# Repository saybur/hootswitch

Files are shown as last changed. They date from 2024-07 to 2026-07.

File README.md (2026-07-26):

hootswitch
==========

Hootswitch is an [ADB](https://en.wikipedia.org/wiki/Apple_Desktop_Bus)
multiplexer that allows peripherals (inluding keyboards and mice) to be shared
across up to four retro computers.

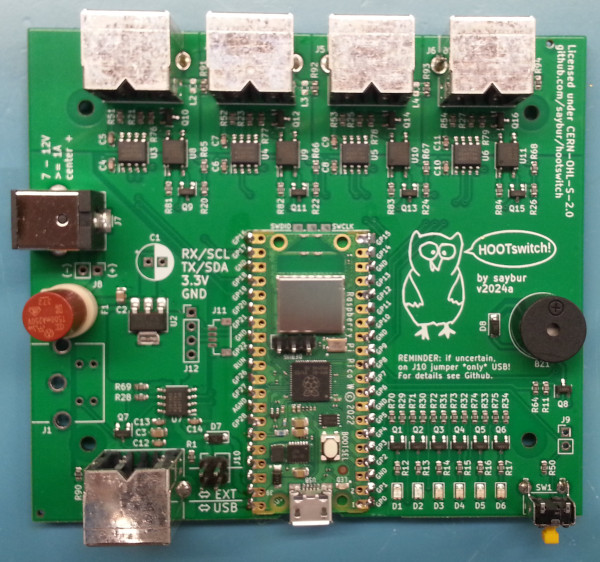
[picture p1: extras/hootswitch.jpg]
Hootswitch 2024a


This project has two parts: an example hardware design and the firmware,
located in their respective folders in this repo.

Status
------

Hootswitch is a hobby project and is very much an ongoing work-in-progress.
Bug reports and/or suggestions are welcome.

Devices that follow the standard ADB keyboard/mouse protocol are supported.
This includes most peripherals that do not have a Mac extension. While ADB was
popular many vendors created devices that required special drivers. There is
interface support for some of these:

- Kensington trackballs (Turbo Mice 4.0 and 5.0)
- Gravis joysticks (Firebird / Blackhawk / Mousestick II)

There is also experimental support for Bluetooth peripherals (both classic and
BLE) via the [Bluepad32](https://github.com/ricardoquesada/bluepad32) library.
Supported devices include
[keyboards](https://bluepad32.readthedocs.io/en/latest/supported_keyboards/),
[mice](https://bluepad32.readthedocs.io/en/latest/supported_mice/), and
[gamepads](https://bluepad32.readthedocs.io/en/latest/supported_gamepads/). By
default, gamepads default to emulating an eight-button keyboard; if you have
the Gravis Firebird driver installed on a computer the gamepad will instead
emulate that device as the extension loads.

Finally, a [fly-by-wire](https://saybur.github.io/hootswitch/flybywire/)
interface allows you to drive your retro computers from a Chromium web browser
on a modern system; this requires a direct USB connection to the Hootswitch.

The firmware is still under active development and many bugs remain. Known
issues include:

- Mouse input can be a bit "floaty" especially during extreme movements.
- No support for non-English keyboard layouts (yet).

This section will continue to be updated as progress is (hopefully) made.

Usage
-----

Hootswitch requires power to operate. For almost all users the front USB
connection of the Pico W works best. Place a jumper across (or permanently
solder) the two front-most pins on J10.

> [!CAUTION]
> __ADB does not support hot-plugging!__ Always power down the device and all
> connected computers before changing cables.

Attach ADB peripherals to the front ADB port. The port on the side of the board
(unpopulated in the picture above) may also be soldered down to provide an ADB
pass-through for more peripherals. Attach computers to the back ports; with
the USB port pointing toward you, computer 1 is the left-most port.

Switching between systems works via the button on the front or
<kbd>Control</kbd> / <kbd>Option</kbd> / <kbd>⌘</kbd> / <kbd>Shift</kbd> in
sequence, followed by <kbd>1</kbd> - <kbd>4</kbd> to choose a port.

To pair a Bluetooth device, put it into pairing mode. Once done, press and hold
the Hootswitch button for at least three seconds, then let go. The Pico W LED
will flash while in pairing mode. More LEDs will light up and the buzzer will
play a tone as the device connects. Hold down the button for more than ten
seconds to remove all paired devices from memory.

Hootswitch logs its status over the USB connection, which may help diagnose
issues with device pairing (or other problems). To view the log, use your
favorite terminal emulator or the fly-by-wire interface.

To update the firmware, make sure your power selection is set for USB, then
hold down the BOOTSEL button while you plug in to your computer via USB. Copy
the correct `.uf2` onto the new mass storage device that appears. Once done the
Pico will disconnect automatically.

Licenses
--------

Except where otherwise noted, all software is available under the Mozilla
Public License (MPL) 2.0. The example hardware is available under the CERN Open
Hardware Licence strongly-reciprocal variant, version 2. Refer to the licenses
for specific terms.

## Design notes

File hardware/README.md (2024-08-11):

Hootswitch Hardware
===================

This folder has the hardware design being used to develop the firmware. Known
issues with it include:

- Some features are untested, including alternate power modes.
- C1 in the BOM is wrong. Since I am not using the power input at the moment I
  left it unpopulated.
- There is no keepout for the wireless chip, which may negatively impact
  reception.
- Annular rings on the mini-DIN connectors are on the small side.
- Green LEDs are too bright. Adjusted in 2024a with PWM. Future revision needs
  stronger resistors.
- Mounting holes are too small for the standard screws. These are also a tad
  too close to the connectors.
- A connection should be made between host power-on and a free GPIO. This can
  be worked around in software with keyboards.
- It might have been wiser to put bus input pins to GPIOs with PWM B inputs.
  This will probably not be changed, PIO handles everything fine.

Anticipate that a future revision will be made with corrections.
[CHANGES.txt](CHANGES.txt) will have any applicable history.

This project is made available under the CERN Open Hardware Licence
strongly-reciprocal variant version 2, available at [LICENSE](LICENSE).

This is distributed WITHOUT ANY EXPRESS OR IMPLIED WARRANTY, INCLUDING OF
MERCHANTABILITY, SATISFACTORY QUALITY AND FITNESS FOR A PARTICULAR PURPOSE.
Please see the CERN-OHL-S v2 for applicable conditions.

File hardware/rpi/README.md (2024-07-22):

# Raspberry Pi Pico Files

See `LICENSE` for distribution. See
<https://github.com/HeadBoffin/RP_Silicon_KiCad> for the original source.

The `.kicad_sym` file was derived from the above and retains its license.

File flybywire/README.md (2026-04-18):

Fly-By-Wire
===========

The web portion of the serial link control system used by Hootswitch. Visit
<https://saybur.github.io/hootswitch/flybywire/> to access.

External Dependencies
---------------------

- `simple_keyboard.js` and `simple-keyboard.css` are from the
[Simple Keyboard](https://github.com/hodgef/simple-keyboard) project.
- `keyboard-capture.js` and `keyboard-capture.css` are from the
[IP-KVM-InterFace](https://github.com/SterlingButters/ip-kvm-interface)
project. Refer to those files for license information.

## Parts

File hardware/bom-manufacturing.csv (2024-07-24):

Designator | Comment | Footprint | LCSC Part Number
C2-3 | 10uF | 805 | C15850
C4-14 | 100nF | 603 | C14663
D1 | LED | 805 | C84256
D2 | LED | 805 | C2296
D3-6 | LED | 805 | C2297
D7-8 | B5819W | SOD-123 | C8598
Q1-16 | MMBT3904 | SOT-23 | C20526
R1 | 470ohm | 603 | C23179
R11-17 | 1Kohm | 603 | C21190
R20-34 | 2K2ohm | 603 | C4190
R50-54 | 4K7ohm | 603 | C23162
R64-79 | 10Kohm | 603 | C25804
R81-84 | 330ohm | 603 | C23138
R90-94 | 0ohm | 603 | C21189
U2 | AMS1117-5.0 | SOT-223 | C6187
U3-7 | ADUM1201ARZ-RL7 | SOIC-8 | C9669
U8-11 | EL357N(C) | SOP-4-2.54mm | C29981

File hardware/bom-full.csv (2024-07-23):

refs | count | desc | jlcpcb | jlcpcb_fp | digikey | notes | cost_est
BZ1 | 1 | Buzzer |  |  | 668-1456-ND | optional | 1.25
C1 | 1 | 100uF |  |  | P1370-ND |  | 0.3
C2-3 | 2 | 10uF | C15850 | 805 |  |  | 0.1
C4-14 | 11 | 100nF | C14663 | 603 |  |  | 0.01
D1 | 1 | LED | C84256 | 805 |  | red | 0.01
D2 | 1 | LED | C2296 | 805 |  | yellow | 0.01
D3-6 | 4 | LED | C2297 | 805 |  | green | 0.01
D7-8 | 2 | B5819W | C8598 | SOD-123 |  |  | 0.02
F1 | 1 | Fuse Holder |  |  | WK0001-ND |  | 0.96
J1-6 | 6 | Mini-DIN-4-G |  |  | 5749181-1-ND | J1 optional | 2
J7 | 1 | Barrel_Jack_MountingPin |  |  | PJ-063AH | optional | 1.61
J8-9 | 1 | 1x2 Pins |  |  | 2057-PH1-02-UA-ND | optional | 0.1
J10 | 1 | 2x2 Pins |  |  | 2057-PH2-04-UA-ND |  | 0.1
J11 | 1 | TWI Connector |  |  | 455-BM04B-SRSS-TBCT-ND | optional | 0.62
J12 | 1 | TWI Connector |  |  | 2057-PH1-04-UA-ND | optional | 0.1
Q1-16 | 16 | MMBT3904 | C20526 | SOT-23 |  |  | 0.01
R1 | 1 | 470ohm | C23179 | 603 |  |  | 0.01
R11-17 | 7 | 1Kohm | C21190 | 603 |  |  | 0.01
R20-34 | 15 | 2K2ohm | C4190 | 603 |  |  | 0.01
R50-54 | 5 | 4K7ohm | C23162 | 603 |  |  | 0.01
R64-79 | 16 | 10Kohm | C25804 | 603 |  |  | 0.01
R81-84 | 4 | 330ohm | C23138 | 603 |  |  | 0.01
R90-94 | 5 | 0ohm | C21189 | 603 |  |  | 0.01
SW1 | 1 | Switch1 |  |  | SW410-ND |  | 0.33
U1 | 1 | Pico W |  |  | 2648-SC0918CT-ND |  | 6
U2 | 1 | AMS1117-5.0 | C6187 | SOT-223 |  |  | 0.15
U3-7 | 5 | ADuM1201AR | C9669 | SOIC-8 |  |  | 1.01
U8-11 | 4 | EL357N(C) | C29981 | SOP-4-2.54mm |  |  | 0.05
- | 1 | switch cap |  |  | SW1139-ND | or similar | 0.95
- | 1 | off-the-shelf case |  |  | HM1093-ND | RM2015S | 6.08
- | 2 | 500mA Fuses |  |  | WK4241BK-ND |  | 0.92

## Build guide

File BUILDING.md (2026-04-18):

Building
========

## Setup

You will need the correct tools to build the firmware. There is a setup script
[here](https://raw.githubusercontent.com/raspberrypi/pico-setup/master/pico_setup.sh)
that assumes you're using a Raspberry Pi as your development environment if you
want to try that; I personally use Debian _trixie_ on a regular x86 system
instead, set up as follows.

Dependencies and associated tools:

```
sudo apt install git cmake gcc-arm-none-eabi gcc gdb-multiarch automake \
    autoconf build-essential texinfo libtool libftdi-dev libusb-1.0-0-dev \
    openocd
```

## Clone the Project

Project dependencies are provided as Git submodules. Clone the project, then
execute `git submodule update --init` within the local working tree. If you do
not have a separate Pico SDK installed you will also need to pull its
submodules with `git submodule update --init --recursive`.

### Optional: Separate pico-sdk

If you have multiple Pico projects (or limited storage space) you may want a
separate copy of the SDK. If `PICO_SDK_PATH` is defined that will be used
instead of the submodule. This part can be skipped if you already used the
`--recursive` version above.

Clone the [Pico SDK](https://github.com/raspberrypi/pico-sdk). Execute
`git submodule update --init` in that project to get sub-libraries added. Set
`PICO_SDK_PATH` to point at where the SDK lives via `~/.bashrc` or equivalent;
something like `export PICO_SDK_PATH=/home/saybur/src/pico-sdk` would be
suitable after being adjusted for your environment.

## Build the Firmware

Once you have everything set up, build as follows from the root of the repo.
This builds for the Pico W by default. To build for the standard (non-W) Pico,
pass `-DPICO_BOARD=pico` during the call to `cmake` below.

```
mkdir -p build
cd build
cmake ..
make -j4
```

Among other files, this will produce `hootswitch.uf2`. Flash it to the device
following the instructions in <README.md>.

## Hardware

Both the original Raspberry Pi Pico and Pico W boards are supported. The focus
of development is on the Pico W: in addition to support for Bluetooth, the
current configuration system also requires the _btstack_ library, which is
licensed for use on the Pico W only.

The Pico 2 and Pico 2 W have _not_ been tested and may not work correctly.

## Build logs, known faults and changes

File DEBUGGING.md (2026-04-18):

Debugging
=========

These are notes for a potential way to debug the device during development.
This is how I (@saybur) personally like working on it in a Linux desktop
environment.

Logging
-------

Hootswitch will log some aspects of device detection, host startup, and similar
lifecycle events to the USB CDC device. Connect at 115200 baud, 8-N-1.

Hardware
--------

To capture ADB signals I use an inexpensive logic analyzer compatible with the
`fx2lafw` firmware from the
[sigrok](https://sigrok.org/wiki/Main_Page) project. To sample the device-side
the passthrough ADB connector works great. For one of the hosts you can either
use the second ADB port on a computer that has one (IIci and the like) or a
hacked-together ADB splitter of some kind.

[PulseView](https://sigrok.org/wiki/PulseView) works for reviewing captures. It
works even better with an ADB decoder like
[decoder-adb](https://github.com/tmk/decoder-adb). On my system that had to be
installed in ` ~/.local/share/libsigrokdecode/decoders` in an `adb` subfolder.

Software
--------

You will want to invoke `cmake` with `-DCMAKE_BUILD_TYPE=Debug`.

[The official debugger](https://www.raspberrypi.com/documentation/microcontrollers/debug-probe.html)
is dirt cheap and works reasonably well if you plan to develop on the firmware.
It can be used as follows to upload without needing to fuss with the BOOTSEL
button. Be in the `dialout` group to avoid needing `sudo` all over the place.
OpenOCD can be started as follows.

```
openocd -c "set USE_CORE 0" -f interface/cmsis-dap.cfg -f target/rp2040.cfg \
    -c "adapter speed 5000" -c "rp2040.core0 configure -rtos FreeRTOS"
```

See <https://github.com/raspberrypi/pico-sdk/issues/1622> for a discussion
about `USE_CORE 0` above. The above is fine for now with the current state of
development, which runs only on a single core anyway.

In another terminal, run `gdb-multiarch hootswitch.elf`. Connect to the device
with `target remote localhost:3333` (or automate this step via `~/.gdbinit`).
See [the documentation](https://openocd.org/doc/html/General-Commands.html) for
specifics; the following commands are likely useful (with the caveat that I am
_most definitely_ not an authority on `gdb`):

* `load` will update programming with the current ELF.
* `monitor reset init` will restart and halt for instructions.
* `print X` prints information about something, including variables.
* `br X` adds a breakpoint at X, `del` removes one or more.
* `continue` will proceed, stopping at breakpoints; Ctrl-C halts.
* `finish` completes a function.
* `bt` prints a backtrace, `bt f` prints a backtrace with symbols.
* `up` and `down` moves around the frames of a call.
* `i r` prints registers.
* `p X` prints variable X.
* `p/x *0x0` prints in hex from the address, useful for peripheral registers.
* `i threads` prints information relevant to FreeRTOS thread execution.

Use `arm-none-eabi-size -A hootswitch.elf` to get an idea about RAM usage.

If compiled with `RUNTIME_FREERTOS_REPORTING` additional serial commands are
made available to invoke various FreeRTOS task reporting functions. To use,
invoke `cmake` with `-DRUNTIME_FREERTOS_REPORTING=1`. Refer to `control.h` and
`debug.h` for a list of commands.

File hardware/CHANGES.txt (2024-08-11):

DESIGN CHANGES

Refer to section 3.3.b of the license for information that must be included in
this document.

- 23 July 2024, rev 2024a: first design

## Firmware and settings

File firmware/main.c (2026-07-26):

/*
 * Copyright (C) 2024-2026 saybur
 *
 * This Source Code Form is subject to the terms of the Mozilla Public
 * License, v. 2.0. If a copy of the MPL was not distributed with this
 * file, You can obtain one at https://mozilla.org/MPL/2.0/.
 */

#include <stdio.h>
#include <stdbool.h>
#include "pico/stdlib.h"
#include "hardware/gpio.h"

#include "FreeRTOS.h"
#include "task.h"

#include "button.h"
#include "buzzer.h"
#include "computer.h"
#include "config.h"
#include "control.h"
#include "debug.h"
#include "driver.h"
#include "host.h"
#include "hardware.h"
#include "led.h"
#include "notify.h"
#include "usb.h"

#ifdef HOOTSWITCH_WIRELESS
#include "bt.h"
#endif

#define PROGRAM_NAME       "hootswitch-v20270726b"

#define DEFAULT_STACK      configMINIMAL_STACK_SIZE
#define DEFAULT_PRIORITY   (tskIDLE_PRIORITY + 1U)
#define DISPATCH_PRIORITY  (tskIDLE_PRIORITY + 8U)

// https://stackoverflow.com/a/2220565
#pragma GCC push_options
#pragma GCC optimize ("O0")
void vApplicationStackOverflowHook(TaskHandle_t xTask, char *pcTaskName)
{
	led_error_on();
	dbg_err("___stack overflow!___ %s", pcTaskName);
	while (1);
}
#pragma GCC pop_options

static void init_hardware(void)
{
	led_init();

	buzzer_init();
	host_init();
	computer_init();

	// setup input switch
	gpio_init(SWITCH_PIN);
	gpio_pull_up(SWITCH_PIN);
}

static void init_config(void)
{
	// already performed within BT code, skip
	// config_setup();

	// read core configuration information, and on failure leave at defaults
	uint8_t core;
	if (config_read(CONFIG_OFFSET_BASE, &core, 1)) {
		return;
	}

	if (! (core & 1)) {
		buzzer_enable(false);
	}
}

static void init_task(__unused void *parameters)
{
	// wait for USB enumeration, and for ADB devices to power up themselves up
	busy_wait_ms(1600);

	// handle alternate startup conditions
	switch (control_check_reset()) {
		case RESET_TYPE_DEBUG:
			// wait for a USB UART to connect
			bool led = false;
			while (! stdio_usb_connected()) {
				vTaskDelay(100);
				if (led) {
					led_activity_on();
				} else {
					led_activity_off();
				}
				led = !led;
			}
			led_activity_off();
			break;
	}

	dbg(PROGRAM_NAME);
	led_activity_on();

#ifdef HOOTSWITCH_WIRELESS
	// need btstack loaded to get TLV config
	volatile bool started = false;
	bt_init(&started);
	while (!started) tight_loop_contents();
#endif

	init_config();
	handler_init();

	host_err herr;
	if (herr = host_reset_bus()) {
		dbg_err("host bus reset err %d", herr);
		notify_user(NOTIFY_HOST_INIT_RESET_FAIL);
	}
	busy_wait_ms(1);
	if (herr = host_reset_devices()) {
		dbg_err("host device reset err %d", herr);
		notify_user(NOTIFY_HOST_INIT_NO_DEVICES);
	} else {
		dbg("host reset ok!");
	}

	driver_init();
	computer_start();

	xTaskCreate(computer_task, "computer", DEFAULT_STACK,
			NULL, DISPATCH_PRIORITY, NULL);
	xTaskCreate(host_task, "host", DEFAULT_STACK,
			NULL, DISPATCH_PRIORITY, NULL);
	xTaskCreate(button_task, "button", DEFAULT_STACK,
			NULL, DEFAULT_PRIORITY, NULL);
	xTaskCreate(control_task, "control", configMINIMAL_STACK_SIZE,
			NULL, DEFAULT_PRIORITY, NULL);

	// may be vulnerable to drivers not being hooked but we'll try anyway
	computer_switch(1, true);

	vTaskDelete(NULL);
}

int main(void)
{
	usb_dev_init();
	stdio_init_all();

	init_hardware();
	dbg_init();

	xTaskCreate(init_task, "init", DEFAULT_STACK,
			NULL, DEFAULT_PRIORITY, NULL);
	xTaskCreate(usb_dev_task, "usb_dev", DEFAULT_STACK * 3,
			NULL, configMAX_PRIORITIES - 1, NULL);
	xTaskCreate(dbg_task, "debug", DEFAULT_STACK,
			NULL, configMAX_PRIORITIES - 2, NULL);
	xTaskCreate(notify_task, "notify", DEFAULT_STACK,
			NULL, DEFAULT_PRIORITY, NULL);

	vTaskStartScheduler();
}

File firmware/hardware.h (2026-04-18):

/*
 * Copyright (C) 2024-2026 saybur
 *
 * This Source Code Form is subject to the terms of the Mozilla Public
 * License, v. 2.0. If a copy of the MPL was not distributed with this
 * file, You can obtain one at https://mozilla.org/MPL/2.0/.
 */

#ifndef __HARDWARE_H__
#define __HARDWARE_H__

/*
 * ----------------------------------------------------------------------------
 *     PIN DEFINITIONS
 *   Change these to match your hardware.
 * ----------------------------------------------------------------------------
 *
 * The RP2040 has fewer "gotchas" than other MCUs but there still are some
 * limitations to be aware of if you're trying a new board spin:
 *
 * - LEDs should not be on PWMs shared with other periphals that use the PWM
 *   system, such as the buzzer, or you will need to adjust the LED driving
 *   code.
 * - Generally try to have the _DO lines on PWM_CHB (odd GPIOs), they are the
 *   only ones with duty cycle / frequency measuring. This is not currently
 *   implemented, PIO handles all that stuff, but it might be useful in the
 *   future.
 */

#define LED_ERR_PIN         0
#define LED_ACT_PIN         1
#define LED_C1_PIN          2
#define LED_C2_PIN          3
#define LED_C3_PIN          4
#define LED_C4_PIN          5
#define SWITCH_PIN          6
#define BUZZER_PIN          7
#define A_DO_PIN            26
#define A_DI_PIN            27
#define C1_DO_PIN           18
#define C1_DI_PIN           19
#define C1_PSW_PIN          17
#define C2_DO_PIN           15
#define C2_DI_PIN           16
#define C2_PSW_PIN          14
#define C3_DO_PIN           12
#define C3_DI_PIN           13
#define C3_PSW_PIN          11
#define C4_DO_PIN           9
#define C4_DI_PIN           10
#define C4_PSW_PIN          8

/*
 * First revision hardware has green LEDs that are quite eye-piercing. To tone
 * it down this value is used by LED setting code to tweak the PWM level (from
 * 0-255) of those elements.
 */
#define LED_MACHINE_LEVEL   70

/*
 * ----------------------------------------------------------------------------
 *     RESOURCE DEFINITIONS / ALIASES
 *   Use care changing anything past this line!
 * ----------------------------------------------------------------------------
 */

// "computer" refers to the emulated device ports on the back
#define COMPUTER_PIO        pio0
#define COMPUTER_PIO_IRQ0   PIO0_IRQ_0
#define COMPUTER_COUNT      4

// device DMA units, used to handle initial signal detection and Listen data
#define COMPUTER_DMA_IRQ    DMA_IRQ_1
#define COMPUTER_DMA_IDX    1
#define COMPUTER_DMA_INTS   dma_hw->ints1
#define COMPUTER_0_DMA      6
#define COMPUTER_1_DMA      7
#define COMPUTER_2_DMA      8
#define COMPUTER_3_DMA      9

// additional DMA channel used for handling configuration data
#define CONFIG_DMA_CHAN     5

// "host" refers to the connection with the native peripherals on the front
#define HOST_PIO            pio1
#define HOST_PIO_IRQ0       PIO1_IRQ_0

#define COMPUTER_TIMER      1
#define COMPUTER_TIMER_IRQ  TIMER_IRQ_1
#define HOST_TIMER          0
#define HOST_TIMER_IRQ      TIMER_IRQ_0

#define A_DO_PIN_bm         (1U << A_DO_PIN)
#define C1_DO_PIN_bm        (1U << C1_DO_PIN)
#define C2_DO_PIN_bm        (1U << C2_DO_PIN)
#define C3_DO_PIN_bm        (1U << C3_DO_PIN)
#define C4_DO_PIN_bm        (1U << C4_DO_PIN)

#define A_DO_PIN_bm         (1U << A_DO_PIN)
#define C1_DO_PIN_bm        (1U << C1_DO_PIN)
#define C2_DO_PIN_bm        (1U << C2_DO_PIN)
#define C3_DO_PIN_bm        (1U << C3_DO_PIN)
#define C4_DO_PIN_bm        (1U << C4_DO_PIN)

#endif /* __HARDWARE_H__ */

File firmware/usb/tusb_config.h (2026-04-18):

/*
 * The MIT License (MIT)
 *
 * Copyright (c) 2019 Ha Thach (tinyusb.org)
 *
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
 */

#ifndef _TUSB_CONFIG_H_
#define _TUSB_CONFIG_H_

#ifdef __cplusplus
 extern "C" {
#endif

//--------------------------------------------------------------------+
// Board Specific Configuration
//--------------------------------------------------------------------+

// RHPort number used for device can be defined by board.mk, default to port 0
#ifndef BOARD_TUD_RHPORT
#define BOARD_TUD_RHPORT     0
#endif

// RHPort max operational speed can defined by board.mk
#ifndef BOARD_TUD_MAX_SPEED
#define BOARD_TUD_MAX_SPEED   OPT_MODE_DEFAULT_SPEED
#endif

//--------------------------------------------------------------------
// COMMON CONFIGURATION
//--------------------------------------------------------------------

// defined by board.mk
#ifndef CFG_TUSB_MCU
#error CFG_TUSB_MCU must be defined
#endif

// saybur note: overwritten by lib/tinyusb/hw/bsp/rp2040/family.cmake
// see https://github.com/raspberrypi/pico-sdk/issues/1326
// worked around in usb.c
#ifndef CFG_TUSB_OS
#define CFG_TUSB_OS           OPT_OS_FREERTOS
#endif

// Espressif IDF requires "freertos/" prefix in include path
#if TUP_MCU_ESPRESSIF
#define CFG_TUSB_OS_INC_PATH  freertos/
#endif

// can be defined by compiler in DEBUG build
#ifndef CFG_TUSB_DEBUG
#define CFG_TUSB_DEBUG        0
#endif

// Enable Device stack
#define CFG_TUD_ENABLED       1

// Default is max speed that hardware controller could support with on-chip PHY
#define CFG_TUD_MAX_SPEED     BOARD_TUD_MAX_SPEED

/* USB DMA on some MCUs can only access a specific SRAM region with restriction on alignment.
 * Tinyusb use follows macros to declare transferring memory so that they can be put
 * into those specific section.
 * e.g
 * - CFG_TUSB_MEM SECTION : __attribute__ (( section(".usb_ram") ))
 * - CFG_TUSB_MEM_ALIGN   : __attribute__ ((aligned(4)))
 */
#ifndef CFG_TUSB_MEM_SECTION
#define CFG_TUSB_MEM_SECTION
#endif

#ifndef CFG_TUSB_MEM_ALIGN
#define CFG_TUSB_MEM_ALIGN    __attribute__ ((aligned(4)))
#endif

//--------------------------------------------------------------------
// DEVICE CONFIGURATION
//--------------------------------------------------------------------

#ifndef CFG_TUD_ENDPOINT0_SIZE
#define CFG_TUD_ENDPOINT0_SIZE   64
#endif

//------------- CLASS -------------//
#define CFG_TUD_CDC              1
#define CFG_TUD_MSC              0
#define CFG_TUD_HID              0
#define CFG_TUD_MIDI             0
#define CFG_TUD_VENDOR           0

// CDC FIFO size of TX and RX
#define CFG_TUD_CDC_RX_BUFSIZE   256
#define CFG_TUD_CDC_TX_BUFSIZE   256

// CDC Endpoint transfer buffer size, more is faster
#define CFG_TUD_CDC_EP_BUFSIZE   64

// MSC Buffer size of Device Mass storage
//#define CFG_TUD_MSC_EP_BUFSIZE   512

#ifdef __cplusplus
 }
#endif

#endif /* _TUSB_CONFIG_H_ */

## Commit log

2024-07-22 Initial hardware design for v2024a.
    [hootswitch-computers.kicad_sch, hootswitch.kicad_pcb, hootswitch.kicad_sch]
2024-07-23 Switch to using proper digital isolator for data lines.
    [hootswitch-computers.kicad_sch, hootswitch.kicad_pcb, hootswitch.kicad_sch]
2024-07-23 Refinements for v2024a during BOM creation.
    [hootswitch-computers.kicad_sch, hootswitch.kicad_pcb, hootswitch.kicad_sch]
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2024-07-23 Initial BOM
    [bom-full.csv]
2024-07-23 Add TWI and second DIN connector, update BOM.
    [bom-full.csv, bom-manufacturing.csv, hootswitch.kicad_pcb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]
2024-07-24 hardware v2024a finalized
    [bom-manufacturing.csv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]
2024-07-25 Untested first draft of simple relay-style switch implementation.
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2024-08-01 Snapshot of ongoing development.
    More PIO, including trying to cut out pin interrupts, and the start of a basic program framework.
2024-08-02 Building out more of the basic program framework.
2024-08-04 First command issued on the prototype hardware! :tada:
    Otherwise just lots and lots of other changes, including documentation for what I'm intending the device/handler subsystem to look like.
    [buzzer.c, device.c]
2024-08-04 Initial host reset/readdr function added.
    Performs basic reg3 talk and listen on a Design keyboard!
    Also includes driver and handler API work.
    [host.c]
2024-08-05 Untested prototype of async host, handler API adjustments.
2024-08-07 Idle polling works! (for at least one device)
2024-08-09 Initial device-side tweaks to PIO, mostly trying to reduce CPU IRQs.
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2024-08-10 Move complexity away from timing-sensitive Tlt to attention.
    More of the skeleton for the device/machine written out.
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2024-08-11 Add mouse, basic switching now works.
    Also improved the host iteration stage to get closer to how real computers handle devices.
    Many many bugs remain but this is finally at proof-of-concept stage!
    [computer.c, host.c, main.c]
2024-08-11 Note keepout issue on wireless chip.
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2024-08-12 Smooth out mouse and fix mis-clicking.
    Still a hack but should be an acceptable foundation for a real driver now.
2024-08-14 Minimally functional FreeRTOS task replacement for the main loop.
    [computer.c, host.c]
2024-08-15 Use PIO to avoid inconsistent host-side Tlt timing.
    In addition to better Tlt reliability this removes a major use of the hardware timer and simplifies the host state machine.
    [host.c]
2024-08-15 Remove pin reset for host SM.
    Should no longer be needed with improvements in the PIO/host handler making the xmit routine a bit more deterministic.
    [host.c]
2024-08-15 Bump priority of host/comp dispatchers, add task notifiers for them.
    Keeps the scheduler from wasting time in the busy-loops of the handler/driver poll tasks and reduces the number of lost mouse update events.
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2024-08-16 More robust mouse driver, multiple handler/driver changes.
    Fixes a nasty null bug in the driver reset code and removes the polling methods. Drivers can now roll their own via a FreeRTOS task if they really need this functionality.
    Also made the host reset a one-time event; given ADB can't be hotplugged this is probably fine. Will need a bit more work to finalize this.
    [computer.c, host.c]
2024-08-17 Keyboard driver updated with some of the mouse code changes.
    Queue unused currently, will be integrated in next few commits.
2024-08-18 Change driver id to ref number, reorg driver Talk data store.
    Also SRQ is now by address again.
2024-08-18 Added queue system for drivers, keyboard is much more robust now.
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2024-08-19 New set/offer entries to computer Talk registers.
    Mouse updated to use these. Might be a bit more responsive, still not sure it's 1:1 versus the direct-attached mouse.
2024-08-19 Tweaks to keyboard switch logic based on testing.
2024-08-21 Simple button implementation for switching the active computer.
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2024-08-25 Support for keyboard LEDs and Register 2.
    This will still need handling for locking Caps Lock keys (or errata for users that you probably shouldn't lock and switch)
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2024-09-01 Move basic CDC to custom TinyUSB setup and FreeRTOS task.
    Also move init code to task to allow USB printf() to work during startup.
2024-09-08 Fix issue with errant SRQs getting issued.
    This seems to happen with the keyboards, maybe something to do with the address shuffle? Makes sure the flag gets cleared when there is no data to send.
    [computer.c]
2026-04-05 Split keyboard support into separate files.
    Driver (virtualized interface) and handler (real device) don't need to be together: separate concerns, allow better reuse of the driver side, and make the files a bit more readable.
2026-04-05 Cleanup and bugfixes from previous driver splits.
2026-04-05 Switch serial to use the new mouse/keyboard drivers.
2026-04-05 Split joystick support into separate driver/handler.
    Same idea as with keyboards and mice earlier: separate concerns, code reuse, etc.
2026-04-05 Barebones bluepad32 library integration.
    Doesn't do anything useful yet but is able to see information from a paired BLE mouse, so that's something I suppose.
    [btstack_config.h, main.c]
2026-04-09 Create a single set of virtual devices to pool inputs.
    Idea is to make serial input share with future devices to cut down on the total number of ADB devices on a computer bus.
2026-04-09 Fix un-inited variable caught by -fanalyzer
    [computer.c]
2026-04-09 Minimally-working bluepad32 integration now no longer crashes.
    Previously work was being executed on random threads, an obvious no-no with btstack. See notes in code for the resolution.
    [led.c, main.c]
2026-04-10 Compact virtual mouse movement into smaller ADB submissions via a queue.
    Ironically I think this makes the mouse feel /worse/ but having some non-blocking method to avoid stalling the BT thread is more important. Will tackle junky mouse feel in a later change.
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2026-04-11 Increase priority of virtual mouse sampler.
    Seems to slightly (?) improve virtual mouse tracking but it's hard to tell. This may eventually need to be fixed by moving some work to core1.
2026-04-11 BT scan only on startup or on-demand.
    Invoked either via flybywire or long (>3s) button press.
2026-04-11 Barely-working gamepad support.
    With a PS5 Dualsense this brings the device down to a crawl, particularly with more than 1 BT peripheral (though it's bad all the time). Suspect it's at the limit of processing with everything on 1 c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
2026-04-12 Suppress extra debug statements for now.
    Seems to be causing some stdio stalls, not sure exactly where yet.
2026-04-12 Log system tweaks.
    Time in ms, single printf per call, set bluepad32 to use same format, and add trace logging.
    Was getting intermittent hardfaults before on heavy log activity, hopefully the trace logs will help narrow down what's going on there.
2026-04-12 Fix mouse buttons being pressed on serial startup.
    The mouse send protocol still needs work, it's quite jittery on fast movement.
2026-04-12 Remove old config system in favor of btstack TLV keys.
    Still needs a lot of thought about how to configure the device. I dislike the web interface, considering whether a Mac side client would be better.
    This will also break config on non-W Picos. That's not ideal but I have concerns about the maintainability of the old system, particularly if SMP gets added.
2026-04-13 Give a bit more of a window for BT devices to connect.
2026-04-13 Note changes in device support and add some additional usage information.
2026-04-14 Simplify building for a standard Pico and note lack of testing on Pico 2.
2026-04-14 Trace logging now disabled until a restart triggered by serial request.
2026-04-14 Move rapid-fire debug statements to trace instead.
    These bog down the USB connection and should only be active in special cases.
2026-04-15 Use a queue for thread safety on stdio.
    AFAIK this should be guaranteed by the SDK but I keep having hardfaults from assert failures in that component, hopefully restricting writes to a single thread will stop that.
    [main.c]
2026-04-15 Tweaks to tone down the buzzer.
    No idea if this is "better" but feedback would be appreciated. Or a better algorithm, the buzzer isn't amazing but it still seems like it could be a little less harsh.
    [buzzer.c]
2026-04-16 Allow trace logging to be disabled/enabled via button on fly-by-wire.
2026-04-16 Handle edge case in bluepad32 joystick position data.
2026-04-17 Centralize notifications and add BT connect/disconnect tone.
    Also adds a flash code error system instead of the simple on/off, and makes the error/activity LEDs one-line set/clears.
    The buzzer is no longer an interrupt, which it really didn't need to be with FreeRTOS around.
    [buzzer.c, computer.c, hardware.h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]
2026-04-17 Tweak tasks priorities, move ADB above BT.
    It seems like this does a better job of maintaining good ADB device response and keeps BT from hogging the CPU.
2026-04-18 Add a simple LED set/clear system for BT devices to supplement the buzzer.
    [computer.c, hardware.h, led.c]
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2026-04-18 Switch flybywire to use SLIP to send commands in frames.
    This should be more forward-compatible as new features are added.
    [main.c]
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2026-04-19 Changes to joystick handling.
    Three interwoven items:
    - Back to using x1/y1 and x2/y2 as data representation.
    - Moving gamepads from using throttle/brake to axis_rx/axis_ry, which is (probably?) more useful for the variety of twin-stick gamepads out there.
    - Move digital buttons around to use trigger digitals, I think on typical gamepads these correspond to throttle/brake anyway. This pushed the system button off the mapping.
    All this could probably use a configuration remap system, but honestly I don't use gamepads on Macs enough for this to be a priority. If someone cares enough they're reading this commit and *really* wants that functionality please open an issue to discuss it.
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2026-04-19 Clarify what the reboot button in flybywire does.
2026-04-19 Split trackball support into separate handler/driver file.
    Should be easier to maintain. It also incorporates all the improvements to mouse handling and prunes out the old config system cruft.
2026-04-19 Fix more instances of unsafe interrupt activity.
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
